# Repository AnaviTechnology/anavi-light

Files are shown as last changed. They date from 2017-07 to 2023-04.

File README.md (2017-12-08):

# Anavi Light pHAT

Anavi Light pHAT is an open source hardware Raspberry Pi pHAT (add-on board) for controlling RGB LED strip powered by free and open source software. It features:

* Slot for RGB LED strip
* 12V input for the RGB LED strip
* Slot for PIR motion sensor
* Slots for up to 3 plug and play I2C sensors for temperature, barometric pressure, humidity and light
* UART (Universal asynchronous receiver/transmitter) pins for debugging
* EEPROM

# License

The project is released under the [Creative Commons Attribution-ShareAlike 4.0 International (CC BY-SA 4.0)](https://creativecommons.org/licenses/by-sa/4.0/).

Note: This is a human-readable summary of (and not a substitute for) the [license](https://creativecommons.org/licenses/by-sa/4.0/legalcode).

You are free to:

Share — copy and redistribute the material in any medium or format Adapt — remix, transform, and build upon the material for any purpose, even commercially. The licensor cannot revoke these freedoms as long as you follow the license terms. Under the following terms:

Attribution — You must give appropriate credit, provide a link to the license, and indicate if changes were made. You may do so in any reasonable manner, but not in any way that suggests the licensor endorses you or your use. ShareAlike — If you remix, transform, or build upon the material, you must distribute your contributions under the same license as the original. No additional restrictions — You may not apply legal terms or technological measures that legally restrict others from doing anything the license permits. Notices:

You do not have to comply with the license for elements of the material in the public domain or where your use is permitted by an applicable exception or limitation. No warranties are given. The license may not give you all of the permissions necessary for your intended use. For example, other rights such as publicity, privacy, or moral rights may limit how you use the material.

You will have to provide a link to the original creator of the project http://www.anavi.technology on any documentation or website.

Credit can be attributed through a link to the creator website: http://www.anavi.technology

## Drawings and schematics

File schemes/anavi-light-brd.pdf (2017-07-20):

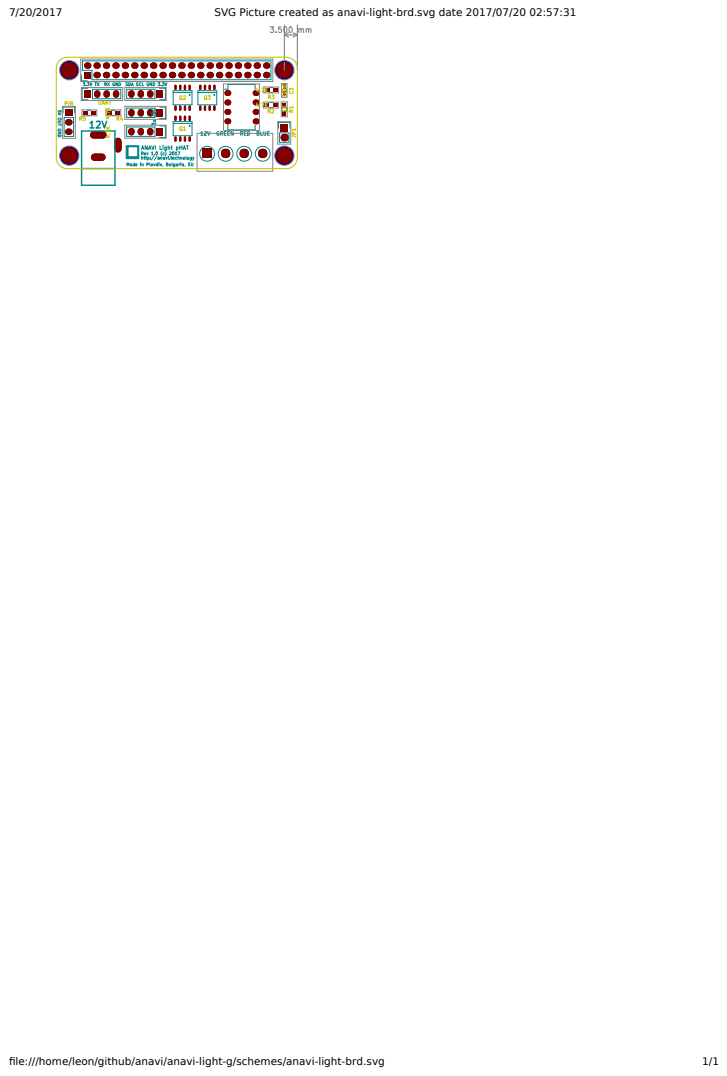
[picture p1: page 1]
SVG Picture created as anavi-light-brd.svg date 2017/07/20 02:57:31; file:///home/leon/github/anavi/anavi-light-g/schemes/anavi-light-brd.svg

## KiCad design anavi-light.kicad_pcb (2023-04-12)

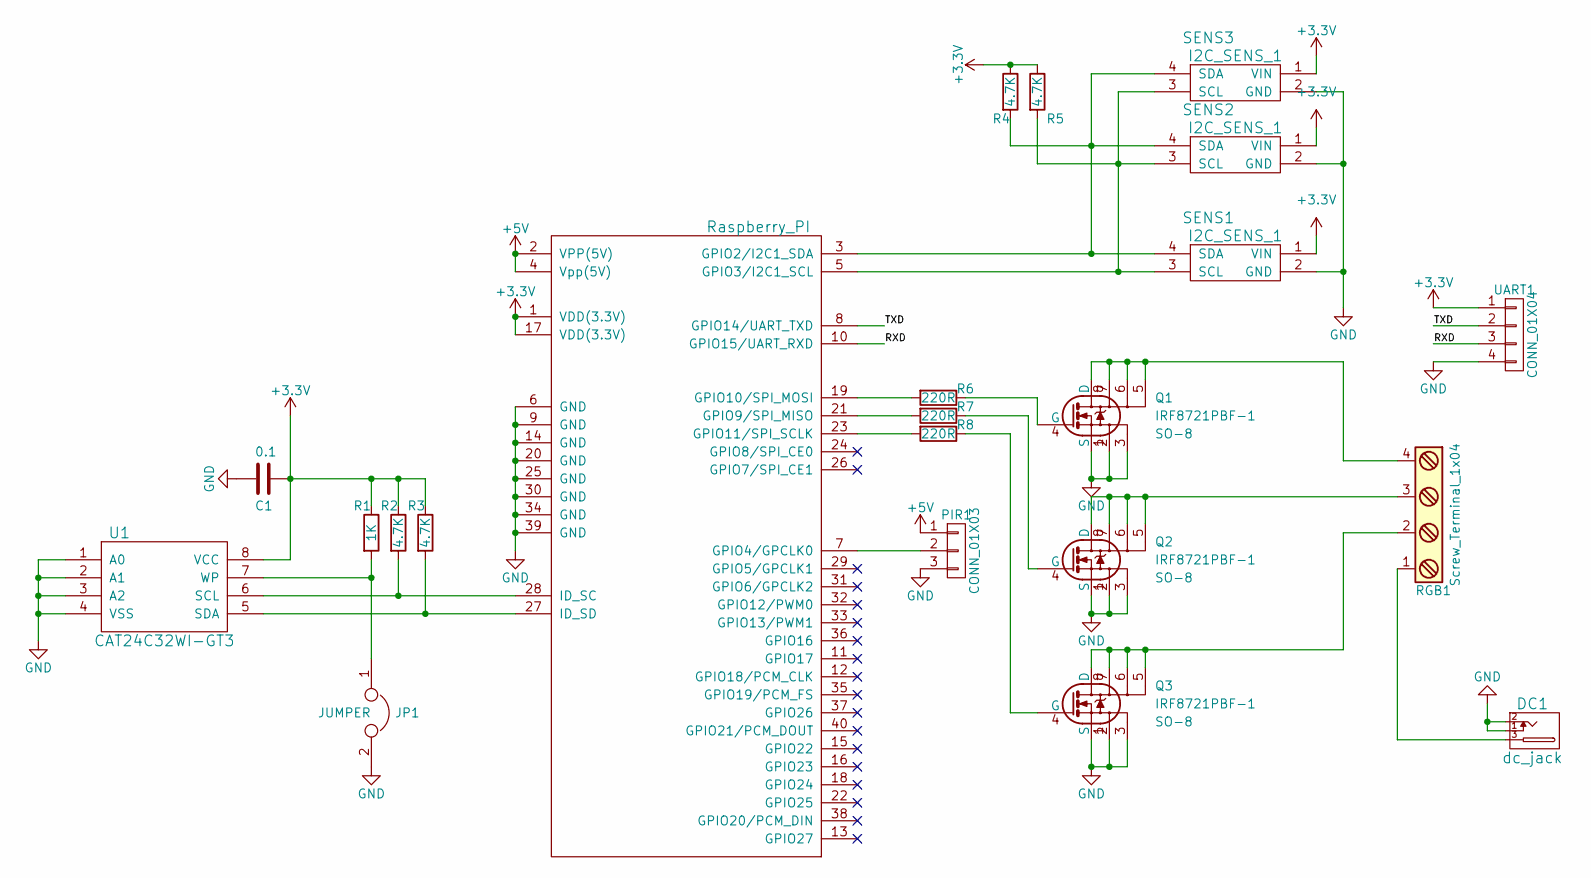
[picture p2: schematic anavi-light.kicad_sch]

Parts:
C1: 0.1; C_0603_HandSoldering
DC1: dc_jack; dc_socket
JP1: JUMPER; Pin_Header_Straight_1x02
PIR1: CONN_01X03; Pin_Header_Straight_1x03
Q1, Q2, Q3: IRF8721PBF-1; SO-8
R1: 1K; R_0603_HandSoldering
R2, R3, R4, R5: 4.7K; R_0603_HandSoldering
R6, R7, R8: 220R; R_0603_HandSoldering
RASP_CONN1: Raspberry_PI; Pin_Header_Straight_2x20
RGB1: Screw_Terminal_1x04; TerminalBlock_Pheonix_MKDS1.5-4pol
SENS1, SENS2, SENS3: I2C_SENS_1; Pin_Header_Straight_1x04
U1: CAT24C32WI-GT3; DIP-8_W7.62mm
UART1: CONN_01X04; Pin_Header_Straight_1x04

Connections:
+3V3: C1.1, R1.1, R2.1, R3.1, R4.1, R5.1, RASP_CONN1.1 (VDD(3.3V)), RASP_CONN1.17 (VDD(3.3V)), SENS1.1 (VIN), SENS2.1 (VIN), SENS3.1 (VIN), U1.8 (VCC), UART1.1; also elsewhere on the board
+5V: PIR1.1, RASP_CONN1.2 (VPP(5V)), RASP_CONN1.4 (Vpp(5V)); also elsewhere on the board
/RXD: RASP_CONN1.10 (GPIO15/UART_RXD), UART1.3; also elsewhere on the board
/TXD: RASP_CONN1.8 (GPIO14/UART_TXD), UART1.2; also elsewhere on the board
GND: C1.2, DC1.1, DC1.2, JP1.2, PIR1.3, Q1.1 (S), Q1.2, Q1.3, Q2.1 (S), Q2.2, Q2.3, Q3.1 (S), Q3.2, Q3.3, RASP_CONN1.6 (GND), RASP_CONN1.9 (GND), RASP_CONN1.14 (GND), RASP_CONN1.20 (GND), RASP_CONN1.25 (GND), RASP_CONN1.30 (GND), RASP_CONN1.34 (GND), RASP_CONN1.39 (GND), SENS1.2 (GND), SENS2.2 (GND), SENS3.2 (GND), U1.1 (A0), U1.2 (A1), U1.3 (A2), U1.4 (VSS), UART1.4; also elsewhere on the board
unnamed: DC1.3, RGB1.1
unnamed: JP1.1, R1.2, U1.7 (WP)
unnamed 7: PIR1.2, RASP_CONN1.7 (GPIO4/GPCLK0); also elsewhere on the board
unnamed: Q1.4 (G), R6.1
unnamed: Q1.5, Q1.6, Q1.7, Q1.8 (D), RGB1.4
unnamed: Q2.4 (G), R7.1
unnamed: Q2.5, Q2.6, Q2.7, Q2.8 (D), RGB1.3
unnamed: Q3.4 (G), R8.1
unnamed: Q3.5, Q3.6, Q3.7, Q3.8 (D), RGB1.2
unnamed: R2.2, RASP_CONN1.28 (ID_SC), U1.6 (SCL)
unnamed: R3.2, RASP_CONN1.27 (ID_SD), U1.5 (SDA)
unnamed: R4.2, RASP_CONN1.3 (GPIO2/I2C1_SDA), SENS1.4 (SDA), SENS2.4 (SDA), SENS3.4 (SDA)
unnamed: R5.2, RASP_CONN1.5 (GPIO3/I2C1_SCL), SENS1.3 (SCL), SENS2.3 (SCL), SENS3.3 (SCL)
unnamed: R6.2, RASP_CONN1.19 (GPIO10/SPI_MOSI)
unnamed: R7.2, RASP_CONN1.21 (GPIO9/SPI_MISO)
unnamed: R8.2, RASP_CONN1.23 (GPIO11/SPI_SCLK)

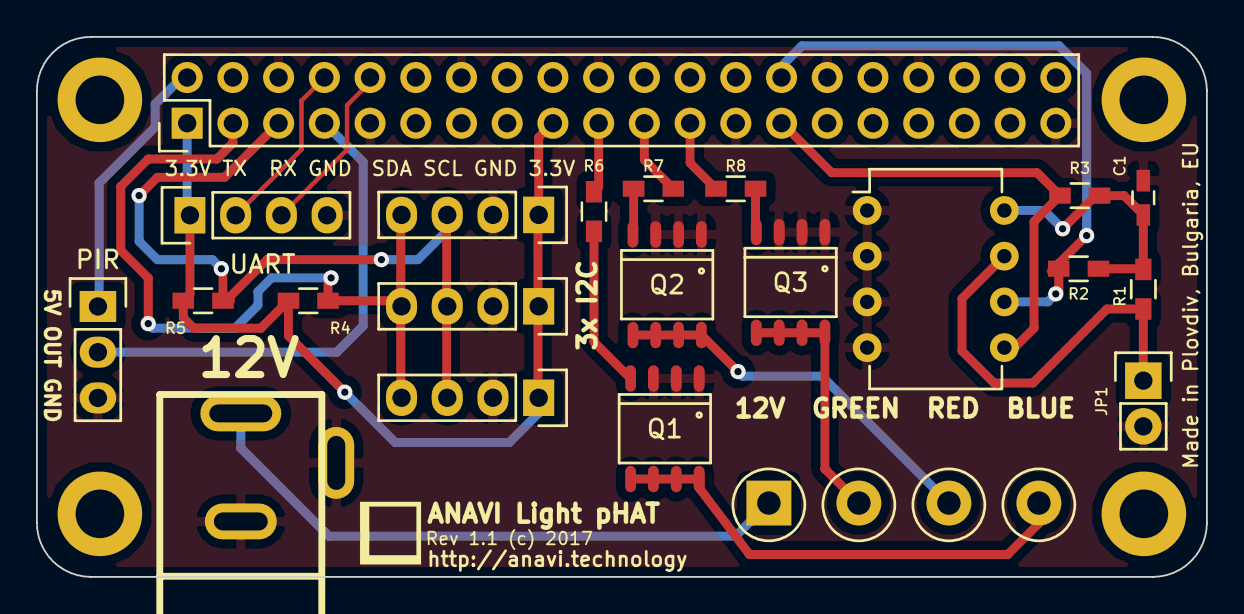
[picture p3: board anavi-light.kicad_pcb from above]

Board: 2 copper layers, 65.0 x 30.0 mm, 26 parts (0 on the bottom side), 21 nets.

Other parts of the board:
PIR: CONN_01X03; Pin_Header_Straight_1x03
REF1, REF2, REF3, REF4: MountingHole_2.7mm_M2.5_DIN965_Pad
UART: CONN_01X04; Pin_Header_Straight_1x04

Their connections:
+3V3: UART.1; also elsewhere on the board
+5V: PIR.1; also elsewhere on the board
/RXD: UART.3; also elsewhere on the board
/TXD: UART.2; also elsewhere on the board
GND: PIR.3, UART.4; also elsewhere on the board
unnamed 7: PIR.2; also elsewhere on the board

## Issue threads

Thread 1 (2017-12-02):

License clarification...

abhas, 2017-12-02:
Hi,

I recently discovered your project via Crowd Supply and was glad to learn about its utility and novelty.

However, I see a contradiction in your licensing and wanted to seek a clarification for the same.

In your README, you state that the project is licensed under the " Creative Commons Attribution-NonCommercial 3.0 Unported (CC BY-NC 3.0)" license. However, elsewhere on the same page you use say that anavi-light is a "open source hardware Raspberry Pi pHAT". This is where I see a contradiction.

The Open Source Hardware (OSHW) definition (available at: https://www.oshwa.org/definition/) clearly states that:

> 4. Derived Works
The license shall allow modifications and derived works, and shall allow them to be distributed under the same terms as the license of the original work. The license shall allow for the manufacture, sale, distribution, and use of products created from the design files, the design files themselves, and derivatives thereof.

> 8. No Discrimination Against Fields of Endeavor
The license must not restrict anyone from making use of the work (including manufactured hardware) in a specific field of endeavor. For example, it must not restrict the hardware from being used in a business, or from being used in nuclear research.

So the CC BY-NC license would conflict with these terms.

What you are doing is really very admirable. I wanted to check if you are aware of such terms regarding OSHW.

Also -- please do submit your project for listing on the OSHWA Certification Directory (http://certificate.oshwa.org/certification-directory/) so that more people might discover your project and be able to use it.

All the best!

leon-anavi, 2017-12-02:
Hi @abhas,

Thank you for the feedback. I wasn't not aware about these details. ANAVI Light pHAT is a hobby project and priority #1 is the community. I am ready change the license in order to make it more community friendly.  Would you recommend me switching to Creative Commons Share-alike 4.0 International or Creative Commons Attribution-Share Alike 3.0 United States License?

Thanks,
Leon

abhas, 2017-12-02:
I think Creative Commons Share-alike 4.0 International should be good. It protects your interests and also provides essential freedom with others.

You can also add that anavi-light is "_Open Source Hardware as defined by the Open Source Hardware (OSHW) Definition 1.0_". This definition is available at: https://www.oshwa.org/definition/

Do check the definition to see that it meets your needs. My reason of raising this issue was that a lot of times people use the term "open source hardware" without really examining the OSHW definition in detail.

Meanwhile, looking forward to your campaign on crowd supply!

leon-anavi, 2017-12-08:
Hi @abhas,

Following your recommendations I have switched the license to CC BY-SA 4.0 in git commit 12eb55df7d9b371fd6cdabf9f96e7d573fa7e152.

Since a few hours the campaign at Crowd Supply is [live](https://www.crowdsupply.com/anavi-technology/light-phat) :)

Thanks,
Leon

Closed 2017-12-08.

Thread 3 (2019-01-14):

Power supply to Pi?

elhaard, 2019-01-14:
Since this pHAT has a 12V input, it would be nice if that 12V could also power the Pi, thus eliminating the need for a separate 5V power supply for the Pi.

leon-anavi, 2019-01-20:
Hi @elhaard,

Yes, although this is an excellent idea I decided not to implement it in Light pHAT due to a several reasons:
* There was not enough physical space on the pHAT for 12V to 5V converter
* Adding a reliable converter for powering the rpi would increase the cost
* Raspberry Pi itself requires quite a lot of power and sometimes could be vagarious to converters therefore the external 12V power supply should be powerful enough for both the RGB LED strip and the rpi

Thank you very much for your interest in the project and for the feedback. Sorry for my late reply. It is definitely an excellent recommendation if we make a full size HAT for a higher price range.

Thanks,
Leon

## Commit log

2017-07-17 ANAVI Light pHAT: Create KiCAD project
    [anavi-light-phat.kicad_pcb, anavi-light-phat.sch]
2017-07-17 Add basic schematics
    [anavi-light-phat.kicad_pcb, anavi-light-phat.sch]
2017-07-18 ANAVI Light pHAT revision 1.0
    [anavi-light-phat.kicad_pcb, anavi-light.kicad_pcb, anavi-light.sch]
2017-07-19 anavi-light: Fixes
    Suggested-by: Rangel Ivanov <rangelivanov88@gmail.com>
    [anavi-light.kicad_pcb, anavi-light.sch]
2017-07-20 Adjust labels on front silkscreen
    [anavi-light.kicad_pcb, anavi-light.sch]
2017-07-20 anavi-light.kicad_pcb: Improve routing
    [anavi-light.kicad_pcb]
2017-08-14 Add MOSFET gate resistors
    [anavi-light.kicad_pcb, anavi-light.sch]
2017-08-14 anavi-light.kicad_pcb: revision 1.1
    [anavi-light.kicad_pcb]
2017-12-08 README.md: CC BY-SA 4.0
    Switch license to CC BY-SA 4.0 to comply with
    the requirements for open source hardware.
2023-04-12 anavi-light: Port to KiCad 6
    Port project to KiCad 6.
    [anavi-light.kicad_pcb, anavi-light.kicad_sch]

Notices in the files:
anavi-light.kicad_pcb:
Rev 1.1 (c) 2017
